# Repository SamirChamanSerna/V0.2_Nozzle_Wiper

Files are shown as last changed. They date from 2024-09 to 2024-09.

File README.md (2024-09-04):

# V0.2_Nozzle_Wiper
Nozzle wiper for purging and cleaning the nozzle of a Voron V0.2. Inspired from the work of [chirpy](https://mods.vorondesign.com/details/xHsmitgNkpdeQ3tpHImI6A "chirpy").

[Nozzle wiper for purging and cleaning the nozzle of a Voron V0.2](https://youtu.be/P-DkkuqNvOA "Nozzle wiper for purging and cleaning the nozzle of a Voron V0.2")

**BOM:**

- 1x Micro Servo 9G Servo Motor (SG90/MG90)
- 1x M3x10mm BHCS
- 1x M2.5x8mm SHCS
- 2x M2x10mm self-tapping screws
- A thin piece of silicone*

*I used a section of a hand sanitizer silicone case

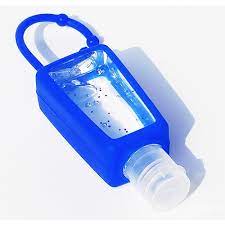
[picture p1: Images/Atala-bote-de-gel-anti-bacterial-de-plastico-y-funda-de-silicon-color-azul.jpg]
example


**Code**

- I modified the chirpy configuration file to make it more suitable for this design.
- You will need to calibrate the routine with the specific values for your printer. The instructions are in the configuration file.
- I also recommend modifying your homing and print start macros for the best integration.

**Renders**

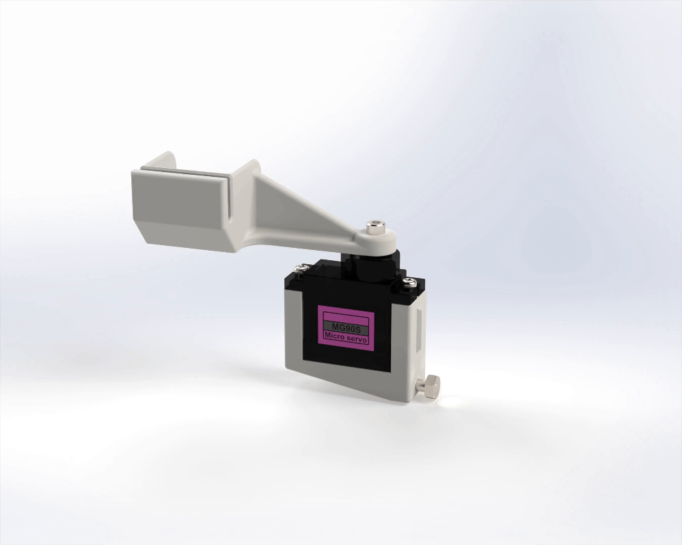
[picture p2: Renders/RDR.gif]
RDR


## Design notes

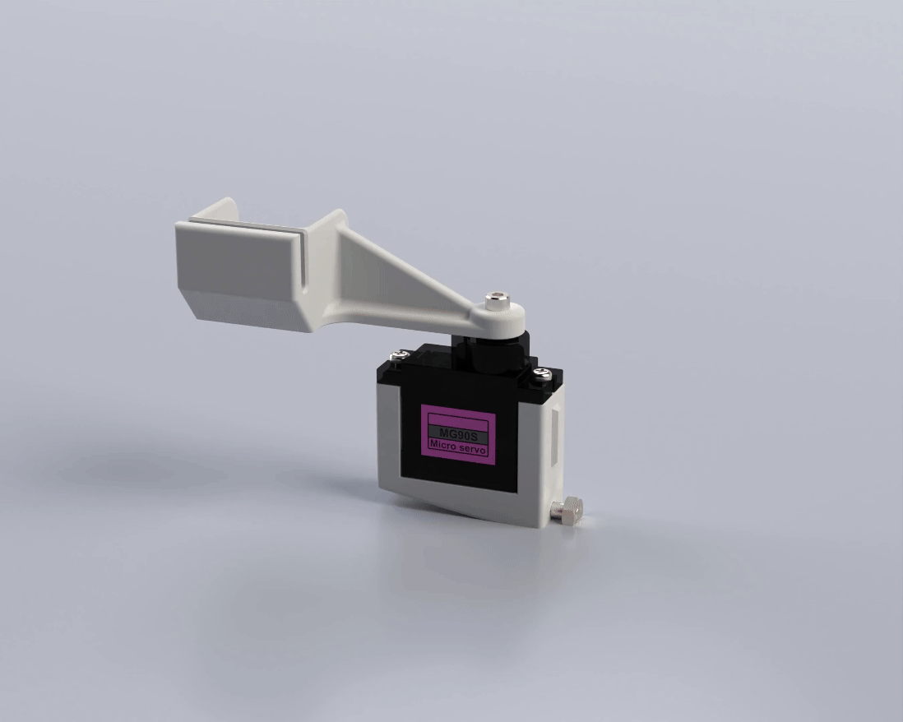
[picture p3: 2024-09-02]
Renders/Spin.gif

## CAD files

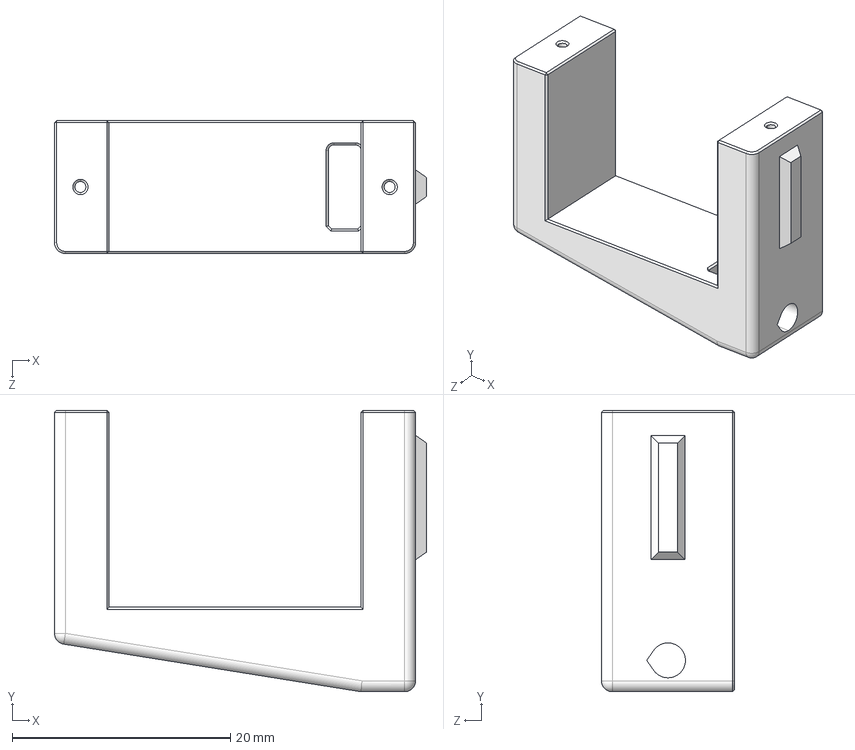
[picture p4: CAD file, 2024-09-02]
CAD/Base Servo (1 Pieza).STEP
34.1 x 25.8 x 12.2 mm

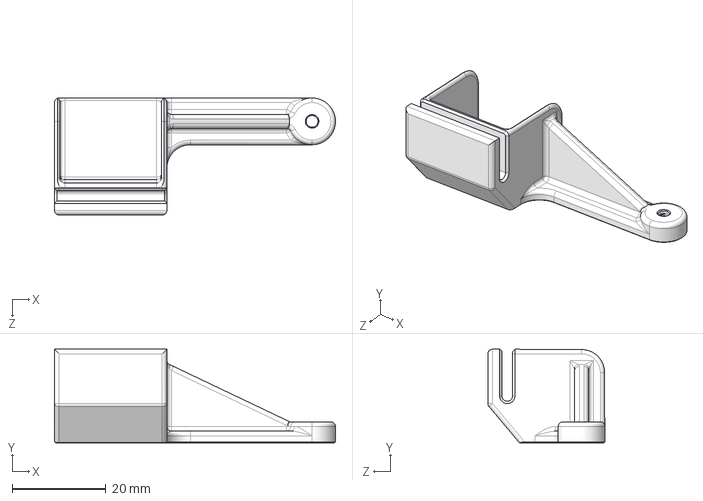
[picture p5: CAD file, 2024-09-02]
CAD/Brazo (1 Pieza).STEP
60.0 x 20.0 x 25.0 mm

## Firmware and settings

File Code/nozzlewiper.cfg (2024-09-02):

###############################################################################
## NOZZLE WIPER - Nozzle wiper for purging and cleaning the nozzle of a Voron V0.2
##
## Configuration:
##
## 1.  Set the correct PWM pin that you connected the Orange wire
##     to in the [servo wipeServo] section replacing XXNN
## 2.  Home X, Y and Z axes
## 3.  Lower Z by at least 50mm
## 4.  Run the NW_DEPLOY macro and ensure the servo extends the arm 90 degrees
## 5.  Use the printer controls to move the nozzle so that it is inline with
##     the brush on the X axis and so that it is in the centre of the purge
##     bucket on the Y axis
## 7.  Run M114 to get the nozzle position and set variable_x and variable_y.
##     If you do not set these values the macro will fail as the defaults are
##     deliberately wrong
## 8.  Move the nozzle into the center of the brush and raise the mount on
##     the extrusion until the nozzle just rests into the brush. Do not let the
##     brush touch the sock or it'll wear it out prematurely
## 9.  Move the nozzle out of the way from the brush and purge bucket
## 10. Run NW_RETRACT and ensure the servo moves the arm back away to the side
##
## Testing:
##
## 1.  Heat the nozzle to the printing temperature of the loaded filament
## 2.  Home all axes
## 3.  Be prepared to hit the Emergency Stop button if things don't go as they
##     should
## 4.  Run NW_CLEAN_NOZZLE
##
## That should be all changes needed. Call the NW_CLEAN_NOZZLE macro from
## the end of your START_PRINT macro to wipe the nozzle clean before printing
###############################################################################

[servo wipeServo]
pin: XXNN
minimum_pulse_width: 0.0005
maximum_servo_angle: 180

[gcode_macro NW_CLEAN_NOZZLE]
gcode:
   {% if "xyz" in printer.toolhead.homed_axes %}
      SAVE_GCODE_STATE NAME=NW_CLEAN_NOZZLE
      G90
      NW_DEPLOY
      NW_PURGE
      NW_WIPE
      NW_RETRACT
      RESTORE_GCODE_STATE NAME=NW_CLEAN_NOZZLE
   {% else %}
      { action_raise_error("Home All Axis First") }
      M117 Home All Axis First
   {% endif %}

[gcode_macro NW_BUCKET_POS]
# Sensible values for variable_x would be 5, but adjust as per the instructions
variable_x: -900000
# Sensible values for variable_y would be around 105, but adjust as per the instructions
variable_y: -900000
# Sensible value for variable_z is 50
variable_z: 50
gcode:
  M118 bucket pos X:{printer["gcode_macro NW_BUCKET_POS"].x} Y:{printer["gcode_macro NW_BUCKET_POS"].y} Z:{printer["gcode_macro NW_BUCKET_POS"].z}

[gcode_macro NW_DEPLOY]
gcode:
    G90
    G0 Z{printer["gcode_macro NW_BUCKET_POS"].z}
    SET_SERVO SERVO=wipeServo ANGLE=120
    G4 P500
    
[gcode_macro NW_RETRACT]
gcode:
    SET_SERVO SERVO=wipeServo ANGLE=60
    G4 P10
    SET_SERVO SERVO=wipeServo ANGLE=90
    G4 P10
    SET_SERVO SERVO=wipeServo ANGLE=0
    SET_SERVO SERVO=wipeServo WIDTH=0 # OFF
    G4 P500

[gcode_macro NW_WIPE]
gcode:
    G90
    G0 Z{printer["gcode_macro NW_BUCKET_POS"].z} F5000
    G0 X{printer["gcode_macro NW_BUCKET_POS"].x} Y{printer["gcode_macro NW_BUCKET_POS"].y} F5000
    {% for wipes in range(1, 4) %}
        G0 X{printer["gcode_macro NW_BUCKET_POS"].x + 30} F{2000}
        G0 X{printer["gcode_macro NW_BUCKET_POS"].x} F{2000}
    {% endfor %}
    G0 X60 F5000
    G0 Y60 F5000

[gcode_macro NW_PURGE]
gcode:
    G90
    G0 Z{printer["gcode_macro NW_BUCKET_POS"].z} F5000
    G0 X{printer["gcode_macro NW_BUCKET_POS"].x} Y{printer["gcode_macro NW_BUCKET_POS"].y} F5000
    {% if printer.extruder.temperature >= 180 %}
       M83
       G1 E20 F300
       G1 E-2 F{150 * 750}
       G4 P{2000}
       G92 E0
    {% else %}
      { action_raise_error("Nozzle Temp must be > 180C") }
    {% endif %}
